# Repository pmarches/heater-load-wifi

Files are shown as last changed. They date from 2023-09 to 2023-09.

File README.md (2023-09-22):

What is this?
---

This repository contains code, drawings and schematics for a device that controls a heating element. This device will throttle the AC current of a device to the duty ratio configured via Wifi. 

The device has features that I could not find in commercial devices;

- Wifi connectivity, for both monitoring and control
- Victron Energy compatible drivers
- Internal temperature monitoring
- External temperature sensor

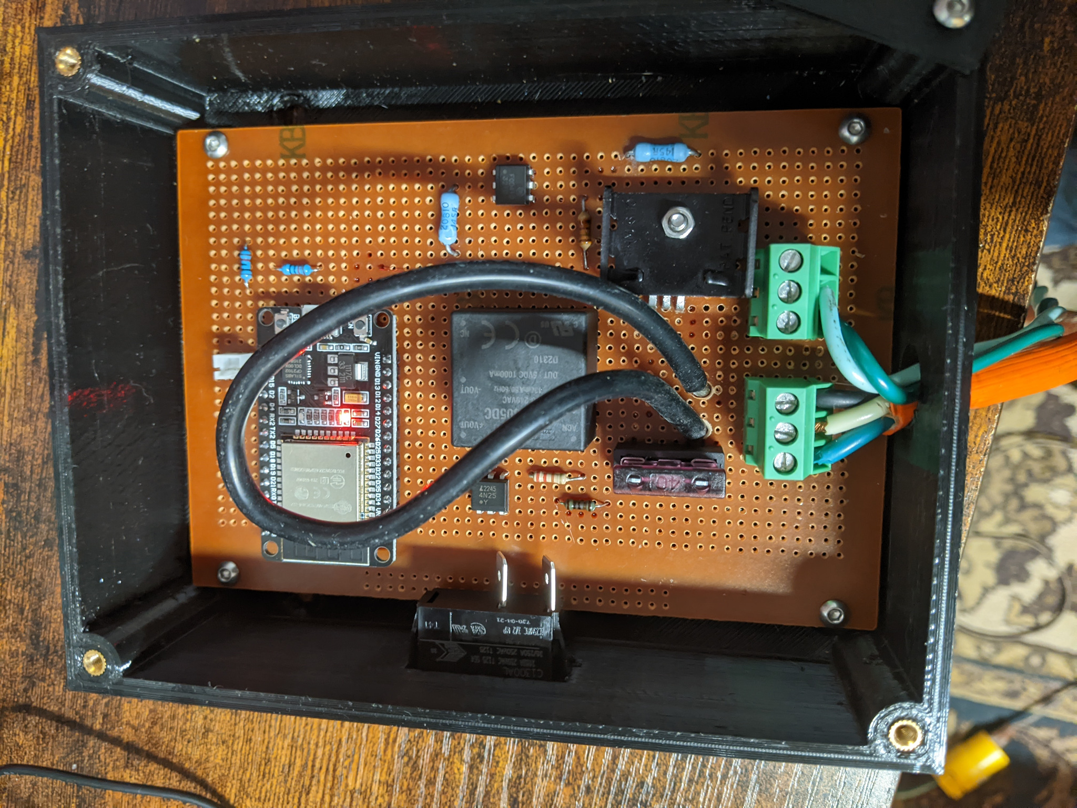
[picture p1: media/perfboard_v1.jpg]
perfboard

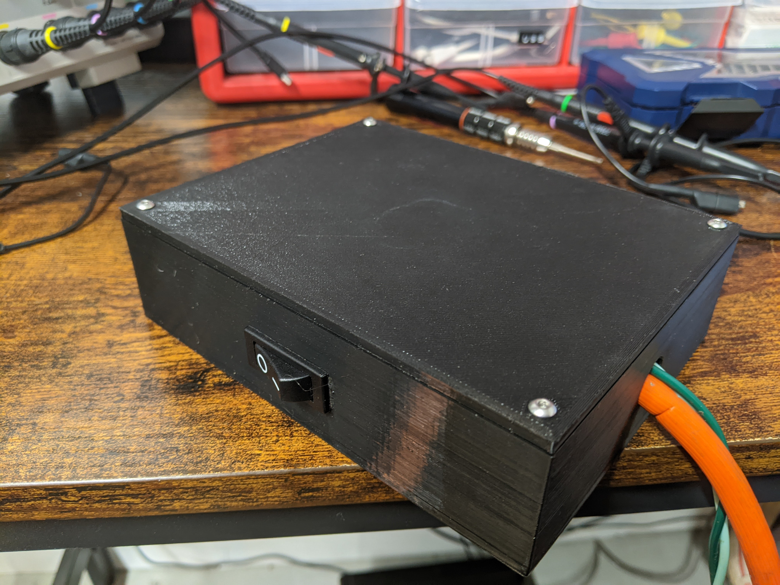
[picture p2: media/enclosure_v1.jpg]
enclosure

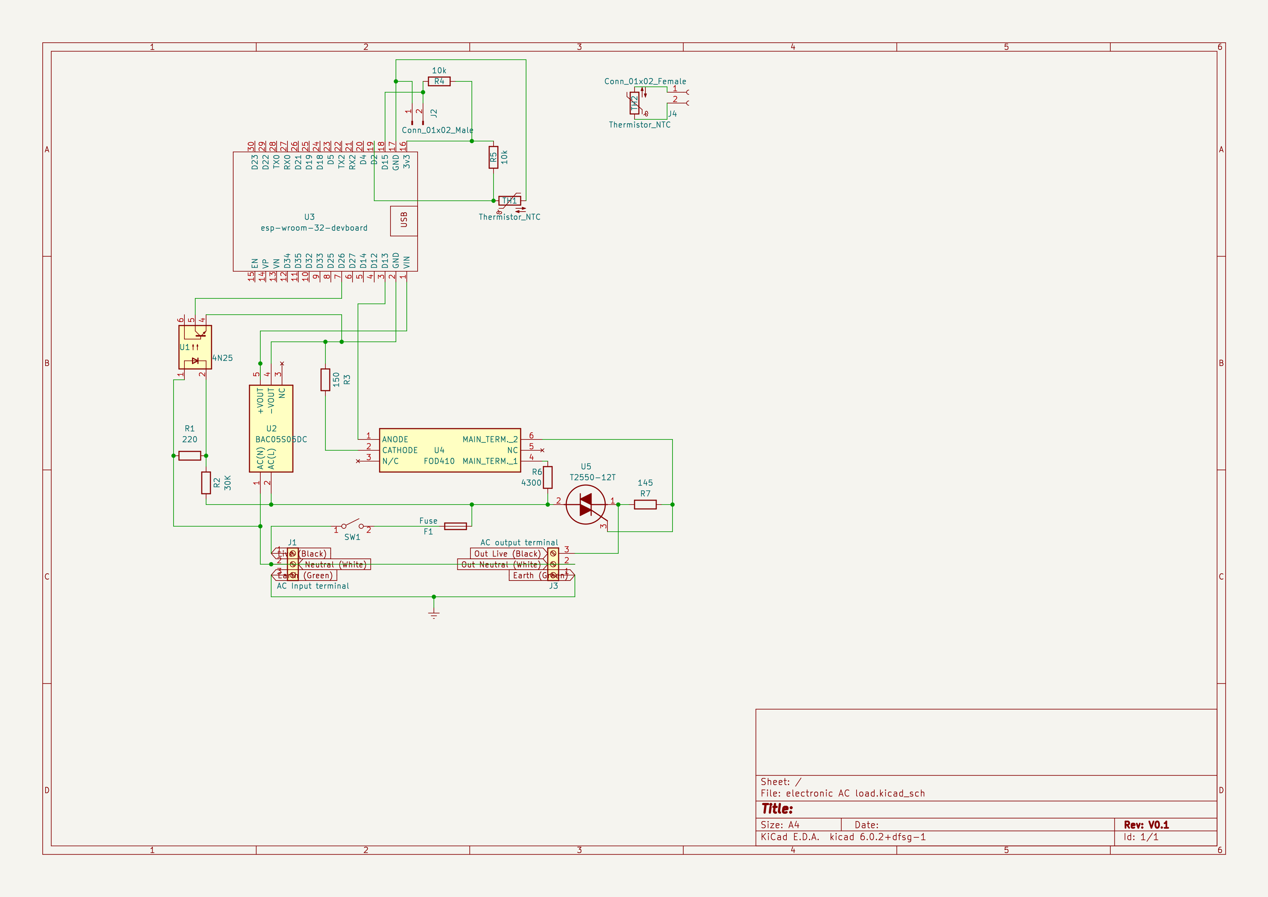
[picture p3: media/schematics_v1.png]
schematics

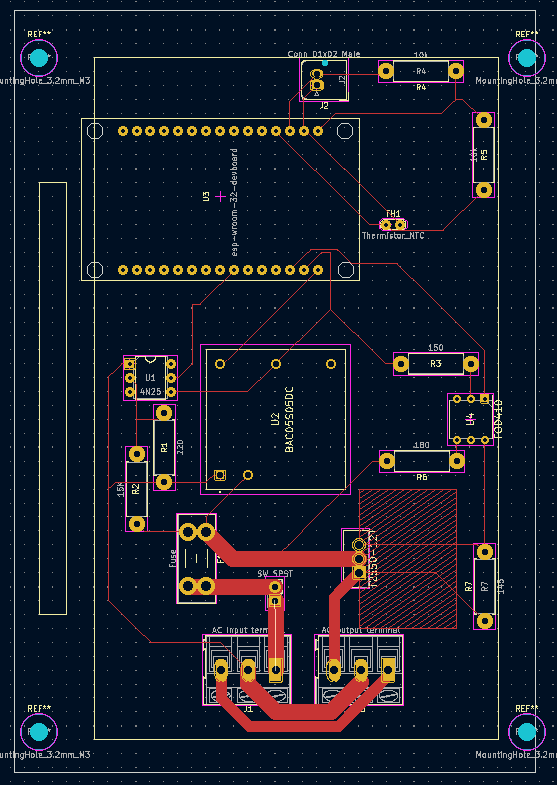
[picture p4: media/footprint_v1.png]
footprint


Use case
---
My use case is to heat water when I have superfluous solar energy. The victron driver knows when it is a good time to start pumping solar energy into heating water. 

Network operation
---
If the device has no Wifi access point configured, it will create one named. "heater load configuration AP". You can then point your web browser to http://10.0.0.1 to set the Wifi credentials and maximum connected load. Reboot the device to see it connect to the confgured AP. The device will advertise itself using MDNS, so you can use mdns-scan or Avahi broswer to get the IP information.

The device has a JSON API on the URL : http://esp32-XXXXXX.local/state the response and payload you can send it looks like this. The included web interface also uses this JSON endpoint.

```json
{
  "onPhaseCount": 1,
  "offPhaseCount": 2,
  "wifissid": "Landlubber",
  "loadWatts": 60,
  "targetWatts": 20,
  "triacTemperatureSensor": 34.63259125,
  "externalTemperatureSensor": null
}
```

The device also has a over the air update mechanism. You can point your browser to the web interface and upload a new firmware.

Victron Operation
---
TBD

Temperature calibration
----
Get the current known temperature from the UI, then record the "ratio" to the current reading. Apply that ratio to all readings. Default ratio is 1.0.

Electrical details
---
We use a TRIAC along with a TRIAC driver to select a certain count of phases from mains AC power.  This avoids the sharp voltage spikes typically associated with TRIACs driven by PWM. This should result in low electrical noise, and low heat loss from the TRIAC. 

The external temperature sensor is just a NTC 10K thermistor with a JST 2.0mm 2 pin connector. 

BOM
---
TBD

TODO
---
- [ ] Add temperature limit
- [ ] Test with higher loads
- [ ] Low power mode
- [ ] Autodetect AC frequency at boot time. Sanity checks for 60Hz
- [ ] Make compatible with 50HZ AC mains. Can it work on 220V ?
- [ ] Test on inverter
- [ ] Monitor TRIAC temperature. Shutdown if too hot.
- [ ] If cannot connect to AP after a few minutes, it should fallback to the temporary AP, to allow re-configuration.
- [ ] Secure configuration page with password.
- [ ] Reduce size of device with printed PCB. Modify enclosure

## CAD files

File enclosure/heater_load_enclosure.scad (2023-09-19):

//$fs=0.1;
$fn=100;

ENCLOSURE_BASE_OUTER_DIM=[121, 155, 40];
ENCLOSURE_BASE_WALL_THICKNESS=4;

module enclosure_base_mount_points(){
  MOUNT_POINT_RADIUS=3;
  X_OFFSET=5;
  union(){
    translate([ENCLOSURE_BASE_WALL_THICKNESS+X_OFFSET, ENCLOSURE_BASE_OUTER_DIM.y*0.8,0]) cylinder(h=ENCLOSURE_BASE_WALL_THICKNESS+5, r=MOUNT_POINT_RADIUS);
    translate([ENCLOSURE_BASE_OUTER_DIM.x-ENCLOSURE_BASE_WALL_THICKNESS-X_OFFSET, ENCLOSURE_BASE_OUTER_DIM.y*0.8,0]) cylinder(h=ENCLOSURE_BASE_WALL_THICKNESS+5, r=MOUNT_POINT_RADIUS);
  }
}

module enclosure_base_wire_hole(){
  translate([ENCLOSURE_BASE_OUTER_DIM.x/2,-1,ENCLOSURE_BASE_OUTER_DIM.z/2]) rotate([-90,0,0]) cylinder(h=ENCLOSURE_BASE_WALL_THICKNESS+10, r=7);
}

module enclosure_base_switch_hole(){
  SWITCH_DIM=[ENCLOSURE_BASE_WALL_THICKNESS+10,31,11];
  translate([-1,ENCLOSURE_BASE_OUTER_DIM.y/2,ENCLOSURE_BASE_OUTER_DIM.z/2]) cube(SWITCH_DIM, center=true);
}

module outer_walls(){
  INNER_SPACE_DIM=ENCLOSURE_BASE_OUTER_DIM-[ENCLOSURE_BASE_WALL_THICKNESS*2, ENCLOSURE_BASE_WALL_THICKNESS*2, 0];
  difference(){
    cube(ENCLOSURE_BASE_OUTER_DIM);
    translate([ENCLOSURE_BASE_WALL_THICKNESS,ENCLOSURE_BASE_WALL_THICKNESS,ENCLOSURE_BASE_WALL_THICKNESS]) cube(INNER_SPACE_DIM);
    enclosure_base_mount_points();
    enclosure_base_wire_hole();
    enclosure_base_switch_hole();
  };
}

module corner_support_one(){
  CORNER_SUPPORT_RADIUS=10;
  CORNER_SUPPORT_SCREW_HOLE_RADIUS=3;
  CORNER_SUPPORT_SCREW_DEPTH=20;
  difference(){
    translate([CORNER_SUPPORT_RADIUS, CORNER_SUPPORT_RADIUS, 0]) cylinder(h=ENCLOSURE_BASE_OUTER_DIM.z, r=CORNER_SUPPORT_RADIUS);
    translate([CORNER_SUPPORT_RADIUS, CORNER_SUPPORT_RADIUS, ENCLOSURE_BASE_OUTER_DIM.z-CORNER_SUPPORT_SCREW_DEPTH+1]) cylinder(h=CORNER_SUPPORT_SCREW_DEPTH, r=CORNER_SUPPORT_SCREW_HOLE_RADIUS);
  }
}

CORNER_SUPPORT_RADIUS=6;
CORNER_SUPPORT_OFFSET=[
  [CORNER_SUPPORT_RADIUS,CORNER_SUPPORT_RADIUS,0],
  [ENCLOSURE_BASE_OUTER_DIM.x-CORNER_SUPPORT_RADIUS,CORNER_SUPPORT_RADIUS,0],
  [CORNER_SUPPORT_RADIUS,ENCLOSURE_BASE_OUTER_DIM.y-CORNER_SUPPORT_RADIUS,0],
  [ENCLOSURE_BASE_OUTER_DIM.x-CORNER_SUPPORT_RADIUS,ENCLOSURE_BASE_OUTER_DIM.y-CORNER_SUPPORT_RADIUS,0],
];
module corner_supports(){
  CORNER_SUPPORT_INSERT_RADIUS=5/2;
  CORNER_SUPPORT_SCREW_DEPTH=20;
  for(i=[0:1:3]){
    translate(CORNER_SUPPORT_OFFSET[i]) difference(){
      cylinder(h=ENCLOSURE_BASE_OUTER_DIM.z, r=CORNER_SUPPORT_RADIUS);
      translate([0, 0, ENCLOSURE_BASE_OUTER_DIM.z-CORNER_SUPPORT_SCREW_DEPTH+1]) cylinder(h=CORNER_SUPPORT_SCREW_DEPTH, r=CORNER_SUPPORT_INSERT_RADIUS);
    }
  }
}


module enclosure_base() {
  outer_walls();
  corner_supports();
  board_supports();
}

BOARD_SUPPORT_OFFSET=[
  [1.5,129,0],
  [90,129,0],
  [1.5,6,0],
  [90,6,0],
];
module board_supports(){
  BOARD_SUPPORT_RADIUS=5;
  translate([14.5,7.5,0]) for(i=[0:1:3]){
    translate([BOARD_SUPPORT_OFFSET[i].x,BOARD_SUPPORT_OFFSET[i].y,0]) difference(){
      cylinder(h=10, r=BOARD_SUPPORT_RADIUS);
      translate([0,0,3]) cylinder(h=8, r=BOARD_SUPPORT_RADIUS/2);
    }
  }
}
module enclosure_cap(){
  SCREW_HOLE_RADIUS=3/2;
  color("blue", alpha=0.8) difference(){
    cube([ENCLOSURE_BASE_OUTER_DIM.x,ENCLOSURE_BASE_OUTER_DIM.y,ENCLOSURE_BASE_WALL_THICKNESS]);
    for(i=[0:1:3]){
      translate(CORNER_SUPPORT_OFFSET[i])
      cylinder(h=ENCLOSURE_BASE_WALL_THICKNESS+1, r=SCREW_HOLE_RADIUS);
    }
  }
}

module vitamin_board(){
  HOLE_RADIUS=3/2;
  HOLE_OFFSET_X=[1,90];
  HOLE_OFFSET_Y=[6.5,129];
  
  VITAMIN_BOARD_POSITION=[ENCLOSURE_BASE_WALL_THICKNESS+9,ENCLOSURE_BASE_WALL_THICKNESS+3, ENCLOSURE_BASE_WALL_THICKNESS+7];
  translate(VITAMIN_BOARD_POSITION) difference(){
    color("green", alpha=0.5) cube([95,140,30]);
    translate([HOLE_RADIUS+HOLE_OFFSET_X[0],HOLE_OFFSET_Y[0],0]) cylinder(h=50, r=HOLE_RADIUS);
    translate([HOLE_RADIUS+HOLE_OFFSET_X[1],HOLE_OFFSET_Y[0],0]) cylinder(h=50, r=HOLE_RADIUS);
    translate([HOLE_RADIUS+HOLE_OFFSET_X[0],HOLE_OFFSET_Y[1],0]) cylinder(h=50, r=HOLE_RADIUS);
    translate([HOLE_RADIUS+HOLE_OFFSET_X[1],HOLE_OFFSET_Y[1],0]) cylinder(h=50, r=HOLE_RADIUS);
  }
}

enclosure_base();
//enclosure_cap();
//vitamin_board();

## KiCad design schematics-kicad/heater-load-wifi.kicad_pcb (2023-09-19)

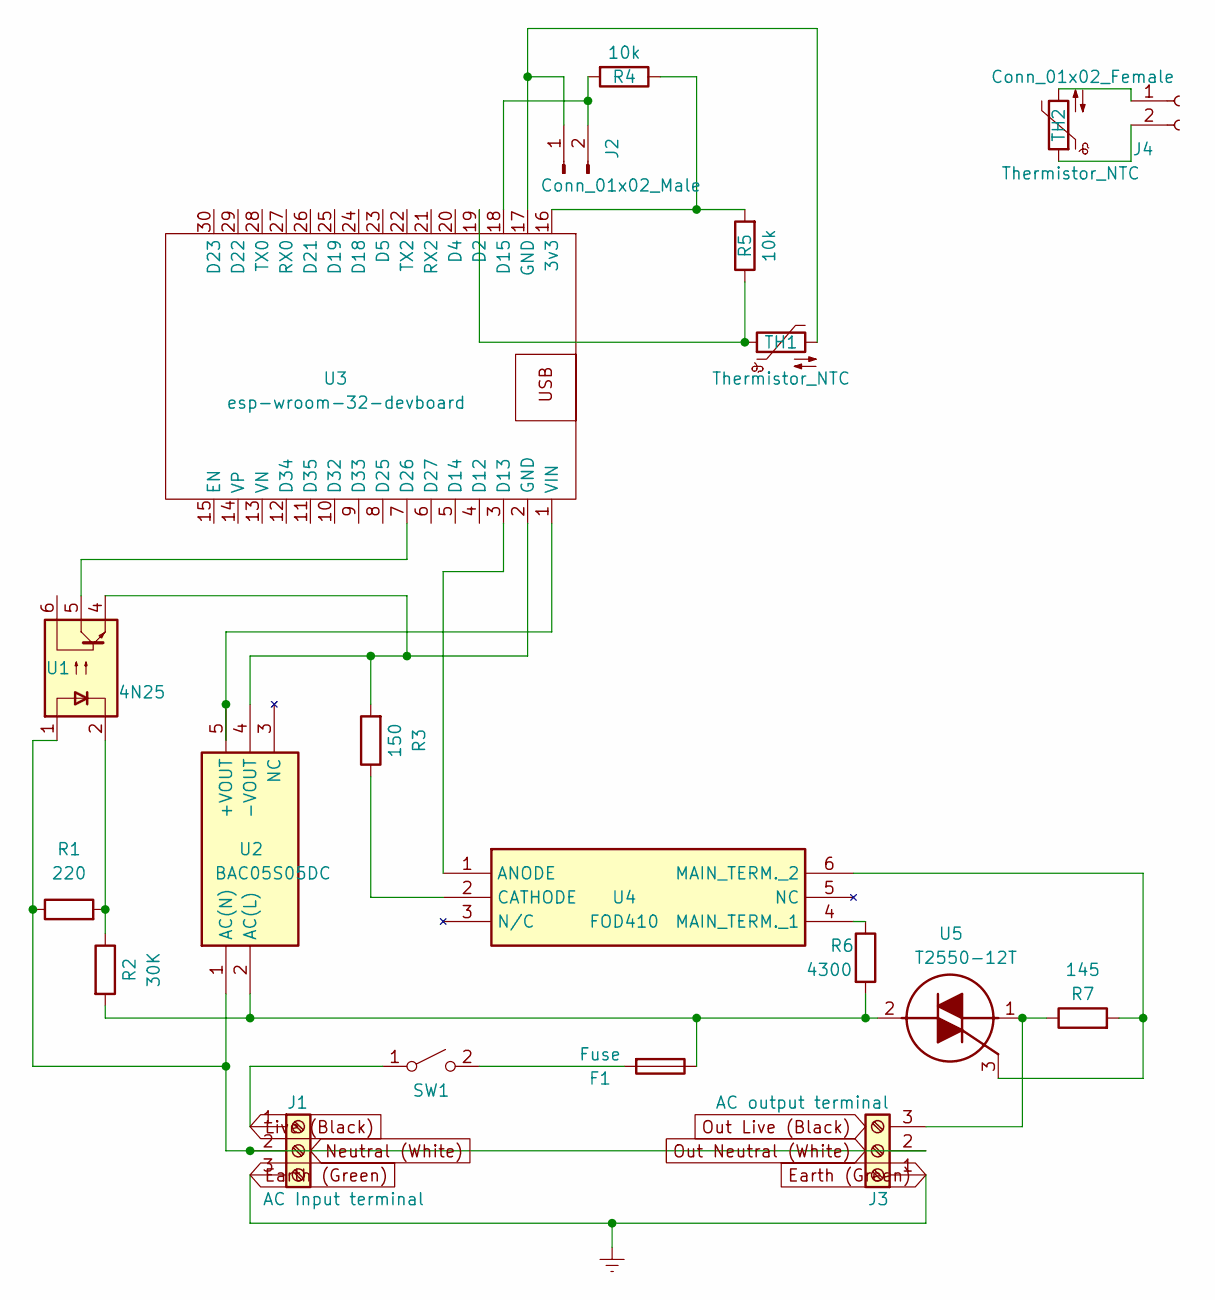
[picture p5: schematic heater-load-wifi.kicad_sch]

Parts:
F1: Fuse; Fuseholder_Blade_Mini_Keystone_3568
J1: AC Input terminal; TerminalBlock_Altech_AK300-3_P5.00mm
J2: Conn_01x02_Male; JST_JWPF_B02B-JWPF-SK-R_1x02_P2.00mm_Vertical
J3: AC output terminal; TerminalBlock_Altech_AK300-3_P5.00mm
J4: Conn_01x02_Female
R1: 220; R_Axial_DIN0411_L9.9mm_D3.6mm_P12.70mm_Horizontal
R2: 30K; R_Axial_DIN0411_L9.9mm_D3.6mm_P12.70mm_Horizontal
R3: 150; R_Axial_DIN0411_L9.9mm_D3.6mm_P12.70mm_Horizontal
R4, R5: 10k; R_Axial_DIN0411_L9.9mm_D3.6mm_P12.70mm_Horizontal
R6: 4300; R_Axial_DIN0411_L9.9mm_D3.6mm_P12.70mm_Horizontal
R7: 145; R_Axial_DIN0411_L9.9mm_D3.6mm_P12.70mm_Horizontal
SW1: SW_SPST; PinHeader_1x02_P2.54mm_Vertical
TH1, TH2: Thermistor_NTC; TestPoint_2Pads_Pitch2.54mm_Drill0.8mm
U1: 4N25; DIP-6_W7.62mm
U2: BAC05S05DC; Mouser Part Number 580-BAC05S05DC
U3: esp-wroom-32-devboard
U4: FOD410; DIP762W60P254L730H450Q6N; Mouser Part Number 512-FOD410
U5: T2550-12T; TO255P460X1020X2005-3P; Mouser Part Number 511-T2550-12T

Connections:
Earth (Green): J1.3, J3.1
Live (Black): J1.1, SW1.1 (A)
unnamed: F1.1, R2.2, R6.2, U2.2 (AC(L)), U5.2 (MT2)
unnamed: F1.2, SW1.2 (B)
unnamed: J2.1, TH1.2, U3.17 (GND)
unnamed: J2.2, R4.2, U3.18 (D15)
unnamed: J3.3, R7.1, U5.1 (MT1)
unnamed: J4.1, TH2.2
unnamed: J4.2, TH2.1
unnamed: R1.2, R2.1, U1.2
unnamed: R3.1, U4.2 (CATHODE)
unnamed: R3.2, U1.4, U2.4 (-VOUT), U3.2 (GND)
unnamed: R4.1, R5.2, U3.16 (3v3)
unnamed: R5.1, TH1.1, U3.19 (D2)
unnamed: R6.1, U4.4 (MAIN_TERM._1)
unnamed: R7.2, U4.6 (MAIN_TERM._2), U5.3 (G)
unnamed: U1.5, U3.7 (D26)
unnamed: U2.5 (+VOUT), U3.1 (VIN)
unnamed: U3.3 (D13), U4.1 (ANODE)
Neutral (White): J1.2, J3.2, R1.1, U1.1, U2.1 (AC(N))

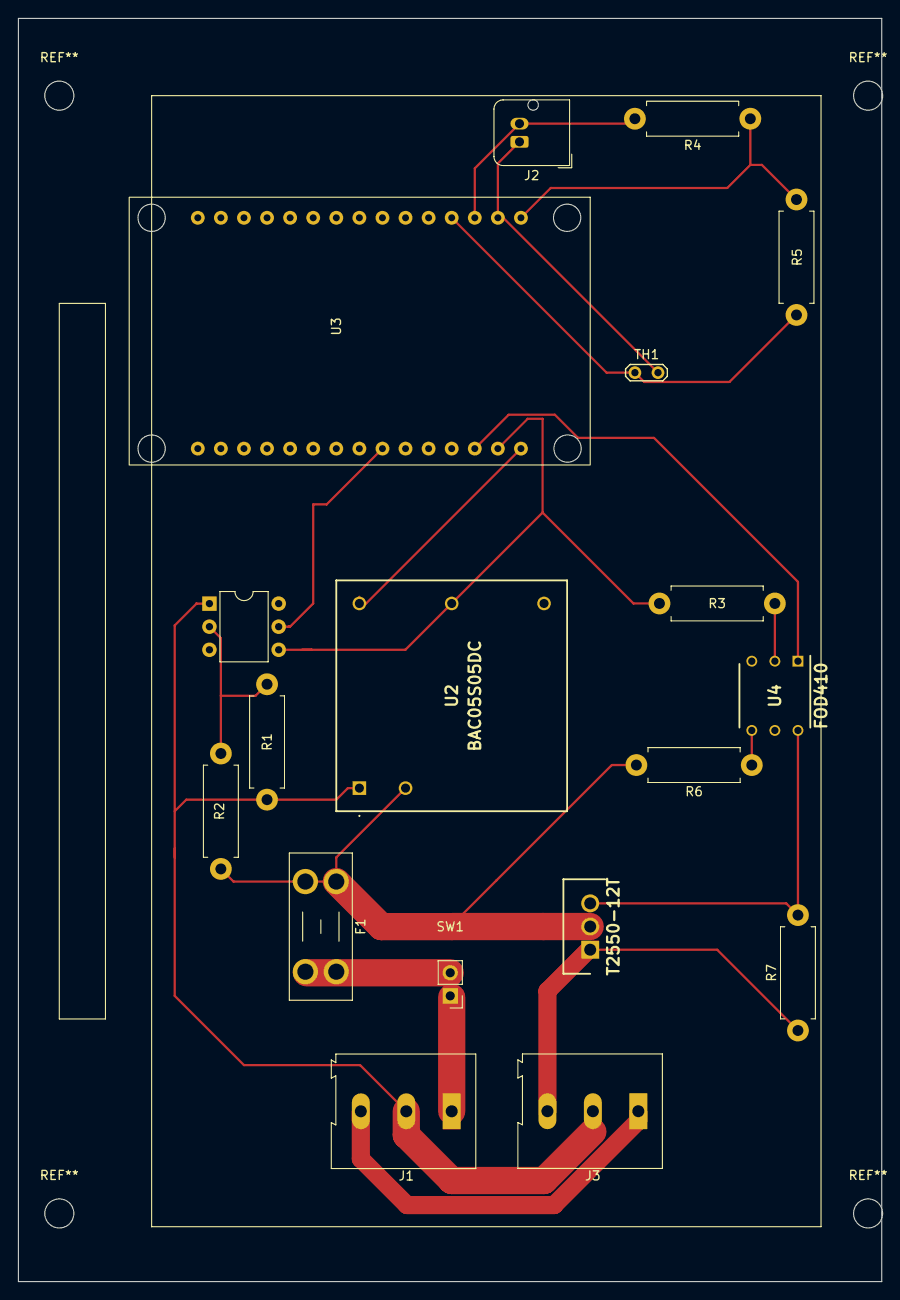
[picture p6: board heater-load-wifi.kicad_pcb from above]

Board: 2 copper layers, 95.0 x 139.0 mm, 18 parts (0 on the bottom side), 18 nets.

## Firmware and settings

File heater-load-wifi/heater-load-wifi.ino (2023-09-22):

#include <ArduinoJson.h>
#include <Preferences.h>

Preferences prefs;

void initWiFi();
void initMDNS();

void initHttp();
void handleHttpClients();
void readTemperatureFromSensors();

void initPWM();
void initTemperature();

void setup() {
  Serial.begin(115200);
  prefs.begin("heater_load");

  initWiFi();
  initMDNS();
  initHttp();

  initTemperature();
  initPWM();
}

void loop(){
  readTemperatureFromSensors();
  handleHttpClients();
  delay(100);
}

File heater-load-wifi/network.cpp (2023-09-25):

#include <Arduino.h>
#include <ArduinoJson.h>
#include <WebServer.h>
#include <ESPmDNS.h>
#include <Update.h>
#include <Preferences.h>

extern Preferences prefs;
void getTemperatureReadings(float& triac, float& external);
void getTemperatureLimits(float& triacTempLimit, float& externalTempLimit);
void setTemperatureLimits(int sensorIndex, float tempLimit);
void setKnownCompensationTemperatureTriac(float knownCurrentTempTriac);
bool isOverTemperature();

extern "C" unsigned char settings_html[];
extern "C" unsigned int settings_html_len;

WebServer server(80);

void handleIncomingJsonMessage(JsonDocument* jsonDoc);

void setTargetWatts(uint32_t targetWatts, uint32_t loadWatts);
uint32_t getTargetWatts();
void setPhaseSelectionCounts(const uint32_t onPhaseCount, const uint32_t offPhaseCount);
void getPhaseSelectionCounts(unsigned int& highCount, unsigned int& lowCount);

void onWiFiStationConnected(WiFiEvent_t event, WiFiEventInfo_t info) {
  Serial.println("Connected to AP successfully!");
}

void onWiFiGotIP(WiFiEvent_t event, WiFiEventInfo_t info) {
  Serial.println("WiFi connected");
  Serial.println("IP address: ");
  Serial.println(WiFi.localIP());
}

void createConfigurationAP(){
  //Create temporary AP to allow first time configuration
  const String TEMP_AP_NAME="heater load configuration AP";
  Serial.printf("Creating temporary access point named %s\n", TEMP_AP_NAME.c_str());
  WiFi.softAP(TEMP_AP_NAME);
}

void doWifiConnect() {
  String ssid=prefs.getString("wifissid");
  if(ssid.length()==0){
    createConfigurationAP();
  }
  else {
    String password=prefs.getString("wifipassword");
    WiFi.begin(ssid, password);
    Serial.printf("Connecting to WiFi %s\n", ssid);
  }
}

void onWiFiStationDisconnected(WiFiEvent_t event, WiFiEventInfo_t info) {
  Serial.println("Disconnected from WiFi access point");
  Serial.print("WiFi lost connection. Reason: ");
  Serial.println(info.wifi_sta_disconnected.reason);
  Serial.println("Trying to Reconnect");

  doWifiConnect();
}

void initMDNS() {
  if (!MDNS.begin(WiFi.getHostname())) {
    Serial.println("Error setting up MDNS responder!");
    while (1) {
      delay(1000);
    }
  }
  Serial.println("mDNS responder started");
  MDNS.addService("heater_load", "tcp", 80);
}

void initWiFi() {
  WiFi.disconnect(true);
  delay(1000);
  char hostname[32] = { '\0' };
  uint8_t eth_mac[6];
  WiFi.macAddress(eth_mac);
  snprintf(hostname, 32, "%s%02X%02X%02X", CONFIG_IDF_TARGET "-", eth_mac[3], eth_mac[4], eth_mac[5]);
  WiFi.setHostname(hostname);

  WiFi.mode(WIFI_STA);
  WiFi.onEvent(onWiFiStationConnected, WiFiEvent_t::ARDUINO_EVENT_WIFI_STA_CONNECTED);
  WiFi.onEvent(onWiFiGotIP, WiFiEvent_t::ARDUINO_EVENT_WIFI_STA_GOT_IP);
  WiFi.onEvent(onWiFiStationDisconnected, WiFiEvent_t::ARDUINO_EVENT_WIFI_STA_DISCONNECTED);
  doWifiConnect();
}

void handleNotFound() {
  String message = F("File Not Found\n\n");

  message += F("URI: ");
  message += server.uri();
  message += F("\nMethod: ");
  message += (server.method() == HTTP_GET) ? F("GET") : F("POST");
  message += F("\nArguments: ");
  message += server.args();
  message += F("\n");

  for (uint8_t i = 0; i < server.args(); i++) {
    message += " " + server.argName(i) + ": " + server.arg(i) + "\n";
  }

  server.send(404, F("text/plain"), message);
}

//TODO Validation of int values. Negatives, MAX, decimals, NaN, ...
void handleJsonCommand(JsonDocument* jsonReq) {
  JsonObject topObject = jsonReq->as<JsonObject>();

  JsonVariant loadWatts = topObject["loadWatts"];
  if(!loadWatts.isNull()){
    prefs.putInt("loadWatts", loadWatts.as<int>());
  }
  JsonVariant targetWattsJson = topObject["targetWatts"];
  if(!targetWattsJson.isNull()){
    setTargetWatts(targetWattsJson, prefs.getInt("loadWatts"));
  }

  JsonVariant onCount = topObject["onPhaseCount"];
  JsonVariant offCount = topObject["offPhaseCount"];
  if (!onCount.isNull() && !offCount.isNull()) {
    //TODO Sanity check here. Negatives, zeroes, ...
    setPhaseSelectionCounts(onCount, offCount);
  }

  JsonVariant wifiSSID = topObject["wifissid"];
  if(!wifiSSID.isNull() && wifiSSID.as<String>().length()>0){
    Serial.println("Updating SSID");
    prefs.putString("wifissid", wifiSSID.as<const char*>());
  }
  JsonVariant wifiPassword = topObject["wifipassword"];
  if(!wifiPassword.isNull() && wifiPassword.as<String>().length()>0){
    Serial.println("Updating password");
    prefs.putString("wifipassword", wifiPassword.as<const char*>());
  }

  JsonVariant triacTemperatureSensor = topObject["triacTemperatureSensor"];
  if(!triacTemperatureSensor.isNull()){
    setKnownCompensationTemperatureTriac(triacTemperatureSensor);
  }

  JsonVariant triacTemperatureLimit = topObject["triacTemperatureLimit"];
  if(!triacTemperatureLimit.isNull()){
    setTemperatureLimits(0, triacTemperatureLimit);
  }

  JsonVariant externalTemperatureLimit = topObject["externalTemperatureLimit"];
  if(!externalTemperatureLimit.isNull()){
    setTemperatureLimits(1, externalTemperatureLimit);
  }
}

void handleStateChange() {
  if(server.args()){
    StaticJsonDocument<200> jsonReq;
    Serial.println("JSON payload is '" + server.arg(0) + "'");
    DeserializationError error = deserializeJson(jsonReq, server.arg(0));
    if (error) {
      server.send(500, F("text/plain"), error.f_str());
      return;
    }

    handleJsonCommand(&jsonReq);
  }

  StaticJsonDocument<200> jsonResponse;
  JsonObject root = jsonResponse.to<JsonObject>();
  unsigned int onPhaseCount;
  unsigned int offPhaseCount;
  getPhaseSelectionCounts(onPhaseCount, offPhaseCount);
  root["onPhaseCount"] = onPhaseCount;
  root["offPhaseCount"] = offPhaseCount;
  root["wifissid"] = prefs.getString("wifissid");
  root["loadWatts"] = prefs.getInt("loadWatts");
  root["targetWatts"] = getTargetWatts();

  float triacTemp=NAN;
  float externalTemp=NAN;
  getTemperatureReadings(triacTemp, externalTemp);
  float triacTempLimit=NAN;
  float externalTempLimit=NAN;
  getTemperatureLimits(triacTempLimit, externalTempLimit);

  root["triacTemperatureSensor"]=triacTemp;
  root["triacTemperatureLimit"]=triacTempLimit;

  root["externalTemperatureSensor"]=externalTemp;
  root["externalTemperatureLimit"]=externalTempLimit;

  root["isOverTemperatureLimit"]=isOverTemperature();

  String jsonBytes;
  serializeJsonPretty(jsonResponse, jsonBytes);
  jsonBytes+="\n";
  server.send(200, F("text/json"), jsonBytes);
}

void handleHttpClients() {
  server.handleClient();
}
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

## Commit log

2023-09-19 Media and readme
    [heater_load_enclosure.scad]
2023-09-19 Kicad schematics
    [heater-load-wifi.kicad_pcb, heater-load-wifi.kicad_sch]
2023-09-19 Arduino code
2023-09-20 Added footprint pic
2023-09-22 Added temperature compensation
2023-09-25 Added temperature limit
